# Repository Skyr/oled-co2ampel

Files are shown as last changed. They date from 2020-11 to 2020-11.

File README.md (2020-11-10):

# CO2-Ampel mit OLED-Display

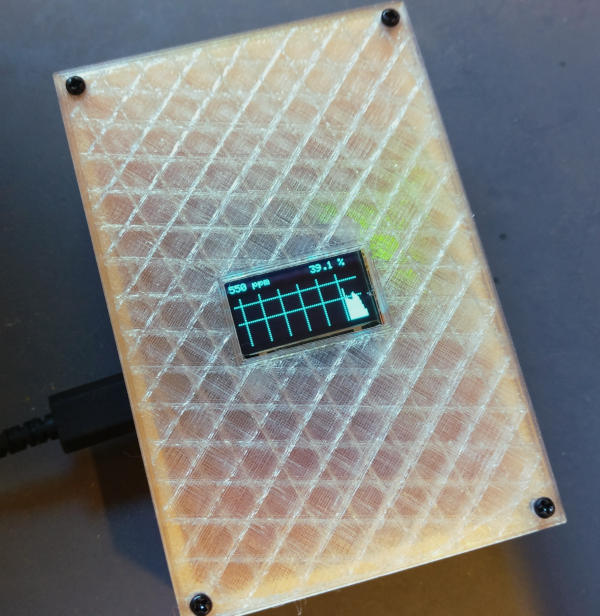
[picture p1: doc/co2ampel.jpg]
Die fertige CO2-Ampel


## Benutzung

### Selbsttest

Nach dem Einschalten führt die Software einen rudimentären Selbsttest aus. Man kann ich auch auf der seriellen Konsole beobachten. Zunächst werden alle LEDs für eine Sekunde eingeschaltet. Wenn keine Fehler auftraten, beginnt die grüne LED zu blinken, bis der erste Messwert vom CO2-Sensor vorliegt.

Andere Blinkcodes haben folgende Bedeutung:

* Rot blinkt: Fehler beim Initialisieren des I2C-Busses (Problem mit Pull-Up-Widerständen?)
* Rotes Licht, gelb blinkt: Der CO2-Sensor reagiert auf dem I2C-Bus nicht (Problem mit Lötstellen? Sensor defekt?)
* Gelb blinkt: Der CO2-Sensor konnte nicht initialisiert werden

### Anzeige

Nach dem Selbsttest geht das Program in den „Ampelmodus“ und aktualisiert alle 15 Sekunden Display und Ampelstatus.
Auf dem Display sieht man die aktuell gemessene CO2-Konzentration sowie die relative Luftfeuchte. Die Balkengrafik zeigt die Historie der Messwerte an. Die senkrechten unterbrochenen Linien sind im Abstand von 5 Minuten dargestellt. Die waagrechten unterbrochenen Linien sind die Schwellwerte für gelbes und rotes Warnlicht.

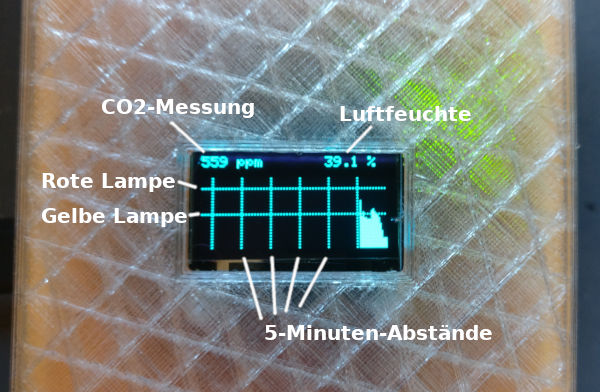
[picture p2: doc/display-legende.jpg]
Display-Legende


### Kalibrieren

Die automatische Kalibrierung des SCD30 erfordert einen ununterbrochenen Betrieb über mindestens 7 Tage hinweg, wobei an jedem Tag mindestens eine Stunde frische Außenluft an den Sensor kommen muss.
Da dies für die üblichen Belange unpraktikabel ist, ist die automatische Kalibrierung abgeschaltet. Stattdessen kann die Kalibrierung von Hand erfolgen:
Hierzu bringt man die CO2-Ampel an frische (bewegungslose) Außenluft (von der angenommen wird, dass sie 406 ppm CO2 enthält) und wartet einige Minuten, bis sich die Messwerte stabilisiert haben.
Nun verbindet man den Pin D3 mit GND (entweder durch Anbringen eines Tasters, oder provisorisch mit z.B. einem Dupont-Kabel). Als Quittung leuchtet die LED des ESP-Moduls. Blinkt sie und erlischt, ist die Kalibrierung abgeschlossen.

## Selber bauen

### Bauteile

* [Octopus-SCD30-Bundle](https://www.tindie.com/products/FabLab/diy-octopus-scd30-bundle-kit/) von Guido Burger
* 0,96" Monochrom-OLED I2C Display-Modul - z.B. von [Amazon](https://www.amazon.de/-/en/AZDelivery-OLED-Parent-Pixel-Inches/dp/B01L9GC470/) oder [AliExpress](https://www.aliexpress.com/item/32638662748.html)
* 12 M2-Schräubchen (3 - 5 mm lang) zum Befestigen der Teile und des Deckels.
* Lötequipment, etwas Kabel zum Anschluss des Displays

### 3d-Gehäuse drucken

Im Verzeichnis 3dprint befinden sie die STL-Dateien für Deckel und Gehäuse,
sowie der Quelltext zur Bearbeitung in [OpenSCAD](https://www.openscad.org/). Beim Druck sollte eine Layer Height von 0,3 genügen (geht schneller ;-).
Für den Deckel sollte ein möglichst durchscheinendes Filament verwendet werden, damit man die Ampel-LEDs gut sieht.

### Zusammenbau

Octopus-Platine nach Anleitung zusammenlöten: Mit den flachen Bauteilen beginnen, etc. Wer will, kann die LED-Beinchen möglichst lange lassen, so dass sie möglichst dicht an den Gehäusedeckel ragen (deshalb das Gehäuse vorher drucken, um die Länge abschätzen zu können) - der man modifiziert das Gehäuse und platziert die LEDs in Aussparungen.

Kabel zum Display befestigen: Diese werden an GND, 5V, D1 und D2 angelötet:

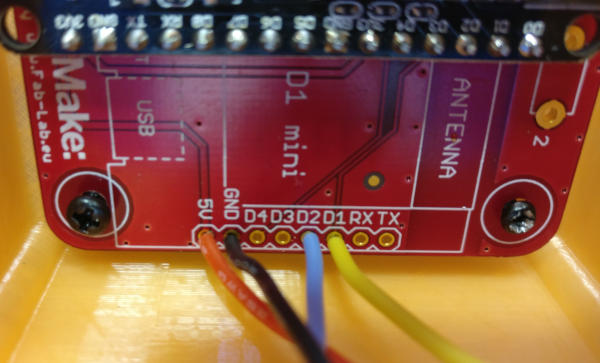
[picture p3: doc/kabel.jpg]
Kabel an der Octopus-Platine


Diese werden am Display-Modul angelötet: 5V führt an VCC, D1 an SCL, D2 an SDA (Beschriftung am Display-Modul beachten! Die sind je nach Hersteller nicht immer in der dargestellten Reihenfolge!)

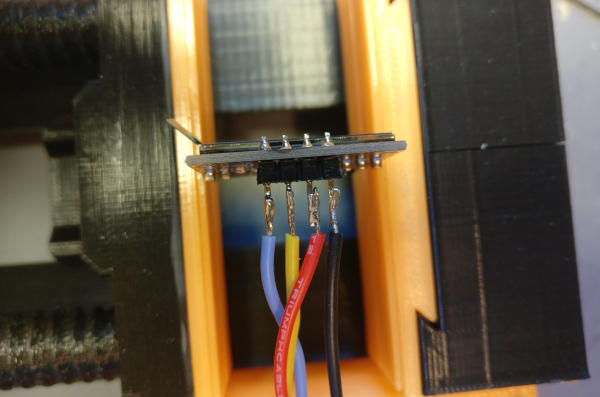
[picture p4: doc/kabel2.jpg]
Kabel am Display-Modul


Nun kann das Display (und, wenn noch nicht geschehen, die Platine) vorsichtig am Gehäuse befestigt werden (beim Display aufpassen, dass man das Glas nicht irgendwo verkantet - es bricht sehr leicht)

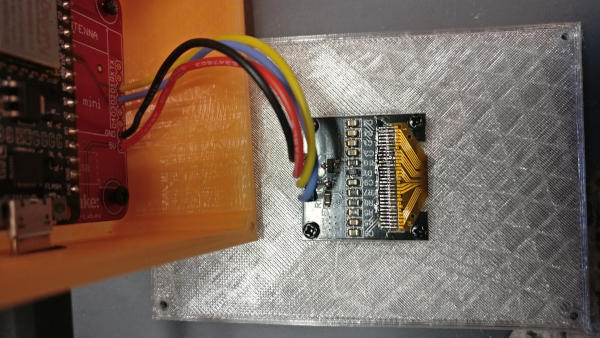
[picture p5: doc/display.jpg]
Displaymodul befestigen


Nun den Deckel auf der Box mit Schrauben befestigen.

### Aufspielen der Firmware

Da die Platine keinen Luftdrucksensor besitzt, sollte vor dem Übersetzen die Konstante `ALTITUDE` auf die (ungefähre) Höhe über NN des Einsatzortes gesetzt werden.
Die Software lässt sich mit dem [PlatformIO-Plugin](https://platformio.org/) in VSCode übersetzen und auf den ESP spielen.  Standardmäßig sind die Schwellwerte für gelb auf 1000 ppm und rot auf 1500 ppm konfiguriert. Dies lässt sich mit den entsprechenden Konstanten anpassen.

## Lizenz

Dieses Projekt (Software, 3D-Modell) steht unter der [Creative-Comons-Lizenz Namensnennung-Nicht kommerziell-Share Alike 4.0 International](https://creativecommons.org/licenses/by-nc-sa/4.0/deed.de).

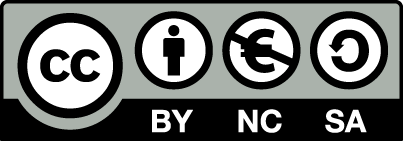
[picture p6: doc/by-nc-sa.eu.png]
CC by-nc-sa


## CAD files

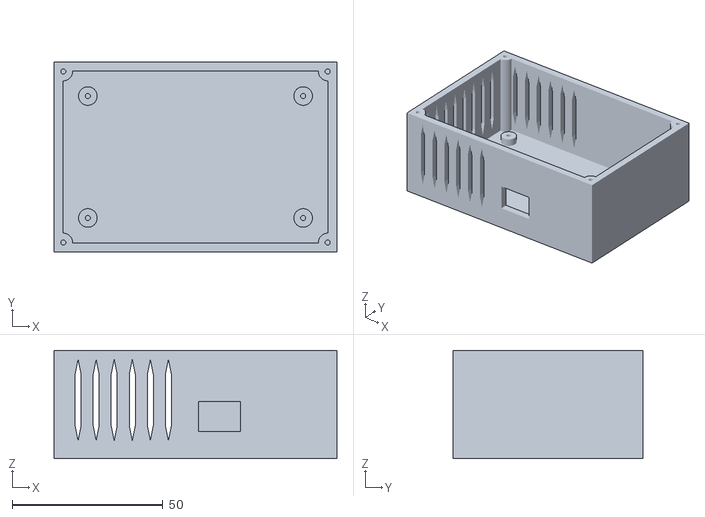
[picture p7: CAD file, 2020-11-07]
3dprint/co2ampel-case-box.stl
94.0 x 63.0 x 36.0

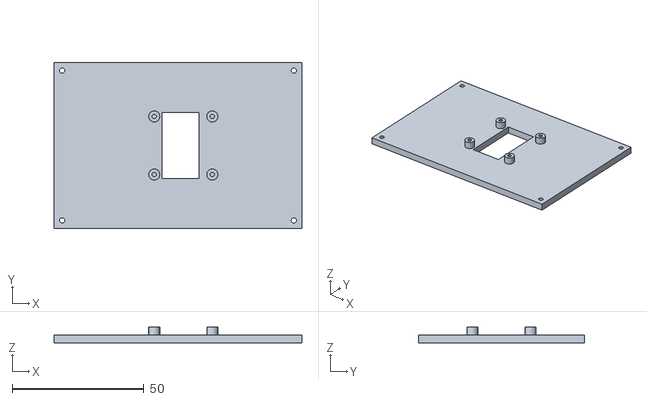
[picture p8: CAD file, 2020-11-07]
3dprint/co2ampel-case-lid.stl
94.0 x 63.0 x 6.00

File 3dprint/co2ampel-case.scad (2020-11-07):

// Written by Stefan Schlott
// Licensed under Creative Commons Attribution-NonCommercial-ShareAlike 4.0 International

wall_thickness = 3;
screw_size = 2; // M2 screw
screwhole_size = 1.7;  // For M2 screws
screwblock_diam = 1.5*wall_thickness + screwhole_size;
board_x = 82;
board_y = 51;
board_spacing = 3;
screw_height = 3;

module screw_opening(height) {
    translate([0,0,height/2]) 
        cylinder(height, d=screw_size, center=true, $fn=30);
}

module screw_hole(height) {
    translate([0,0,height/2]) 
        cylinder(height, d=screwhole_size, center=true, $fn=30);
}

module screw_block(height, diam=screwblock_diam) {
    translate([0,0,height/2]) cylinder(height, d=diam, center=true, $fn=30);
}

module screw_mount(height, diam=screwblock_diam) {
    difference() {
        screw_block(height, diam);
        screw_hole(height);
    }
}

module ventilation_slit(height) {
    width=2;
    translate([0,wall_thickness,0])
    rotate([90,0,0])
    linear_extrude(height=wall_thickness)
        polygon(points=[ [0,0], [-width/2, 5], [-width/2,height-5], [0,height], [width/2,height-5],[width/2,5] ]);
}

module box() {
    board_screw_offset = 5.25;
    electronics_height = 30;

    module outer_box() {
        difference() {
            cube([2*wall_thickness + 2*board_spacing + board_x,
                2*wall_thickness + 2*board_spacing + board_y,
                wall_thickness + screw_height + electronics_height ]);
            translate([wall_thickness,wall_thickness,wall_thickness])
                cube([2*board_spacing + board_x,
                    2*board_spacing + board_y,
                    screw_height + electronics_height ]);
        }
    }

    // Outer box with screw holes
    difference() {
        union() {
            outer_box();
            for (i=[0:1]) {
                for (j=[0:1]) {
                    translate([screwblock_diam/2 + i*(2*wall_thickness + 2*board_spacing + board_x-screwblock_diam), 
                        screwblock_diam/2 + j*(2*wall_thickness + 2*board_spacing + board_y-screwblock_diam),
                        wall_thickness])
                            screw_block(screw_height + electronics_height);
                }
            }
        }
        // Holes for screws
        for (i=[0:1]) {
            for (j=[0:1]) {
                translate([screwblock_diam/2 + i*(2*wall_thickness + 2*board_spacing + board_x-screwblock_diam), 
                    screwblock_diam/2 + j*(2*wall_thickness + 2*board_spacing + board_y-screwblock_diam),
                    wall_thickness + electronics_height ])
                        screw_hole(screw_height);
            }
        }
        // USB opening
        usb_width = 14;
        usb_height = 10;
        translate([wall_thickness+board_spacing+49-(usb_width/2),0,wall_thickness+screw_height+8-(usb_height/2)]) cube([usb_width,wall_thickness,usb_height]);
        // Ventilation slits
        for (i=[0:5]) {
            translate([wall_thickness+board_spacing+2+i*6,0,wall_thickness+screw_height])
                ventilation_slit(electronics_height-screw_height);
            translate([wall_thickness+board_spacing+2+i*6,wall_thickness+2*board_spacing+board_y,wall_thickness+screw_height])
                ventilation_slit(electronics_height-screw_height);
        }
        for (i=[0:7]) {
            translate([wall_thickness,wall_thickness+board_spacing+board_y/2-1+(i-3.5)*6,wall_thickness+screw_height])
            rotate([0,0,90])
                ventilation_slit(electronics_height-screw_height);
        }
    }
    
    translate([0,0,wall_thickness]) {
        for (i=[0:1]) {
            for (j=[0:1]) {
                translate([wall_thickness+board_spacing+board_screw_offset + i*(board_x-2*board_screw_offset),
                    wall_thickness+board_spacing+board_screw_offset + j*(board_y-2*board_screw_offset),
                    0]) screw_mount(screw_height);
            }
        }
    }
    
    // For reference: Board
    //translate([wall_thickness+board_spacing, wall_thickness+board_spacing, wall_thickness+screw_height]) 
    //    color("red")    
    //    cube([board_x, board_y, 2]);
}


module lid() {
    thickness = wall_thickness;
    display_x_ofs = 32;  // Offset from top of board
    display_x_out_of_center = 1;  // Display not exactly in middle of board...
    display_x = 14;
    display_y = 25;
    screw_x_ofs = 4;
    screw_y_ofs = 1.5;
    
    difference() {
        cube([2*wall_thickness + 2*board_spacing + board_x,
            2*wall_thickness + 2*board_spacing + board_y,
            thickness]);
        // Screw holes for mounting the lid
        for (i=[0:1]) {
            for (j=[0:1]) {
                translate([screwblock_diam/2 + i*(2*wall_thickness + 2*board_spacing + board_x-screwblock_diam), 
                    screwblock_diam/2 + j*(2*wall_thickness + 2*board_spacing + board_y-screwblock_diam),
                    0 ])
                        screw_opening(thickness);
            }
        }
        // Display opening
        translate([wall_thickness + board_spacing + display_x_ofs + display_x_out_of_center,(2*wall_thickness + 2*board_spacing + board_y - display_y)/2,0])
            cube([display_x,display_y,thickness]);
    }
    // Screw mounts for display
    translate([wall_thickness + board_spacing + display_x_ofs,(2*wall_thickness + 2*board_spacing + board_y - display_y)/2,-screw_height]) {
        translate([-screw_x_ofs,screw_y_ofs,0]) screw_mount(screw_height, diam = screwhole_size + 2.5);
        translate([display_x+screw_x_ofs,screw_y_ofs,0]) screw_mount(screw_height, screwhole_size + 2.5);
        translate([-screw_x_ofs,display_y-screw_y_ofs,0]) screw_mount(screw_height, screwhole_size + 2.5);
        translate([display_x+screw_x_ofs,display_y-screw_y_ofs,0]) screw_mount(screw_height, screwhole_size + 2.5);
    }
}


translate([0,0,-30 - 20])
    box();
// rotate([0,180,0])
    lid();

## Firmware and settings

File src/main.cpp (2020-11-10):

// Written by Stefan Schlott
// Licensed under Creative Commons Attribution-NonCommercial-ShareAlike 4.0 International


#include <Arduino.h>
#include <Wire.h>

#include <SparkFun_SCD30_Arduino_Library.h>
#include <Adafruit_SSD1306.h>
#include <Adafruit_GFX.h>

// OLED display size, in pixels
#define SCREEN_WIDTH 128
#define SCREEN_HEIGHT 64

Adafruit_SSD1306 display(SCREEN_WIDTH, SCREEN_HEIGHT, &Wire);
SCD30 airSensor;
uint16_t co2buffer[SCREEN_WIDTH+1];

// Pin definitions
#define LED_RED     D6
#define LED_YELLOW  D7
#define LED_GREEN   D5
#define I2C_SCL     D1
#define I2C_SDA     D2
#define CAL_BUTTON  D3

// Altitude (in meters). Atmospheric pressure (and thus the measurement) drops by 3% for every ~300m!
#define ALTITUDE 445
// Number of seconds between measurements
#define UPDATE_INTERVAL 15

#define CO2_BAR_MIN 350
#define CO2_BAR_MAX 1700
#define YELLOW_THRESHOLD 1000
#define RED_THRESHOLD 1500


bool display_enabled = false;
bool do_calibration = false;
unsigned long last_calibration = 0;


void ledsOff() {
    digitalWrite(LED_RED, LOW);
    digitalWrite(LED_YELLOW, LOW);
    digitalWrite(LED_GREEN, LOW);
}

void blink(int pin, int d) {
    digitalWrite(pin, HIGH);
    delay(d);
    digitalWrite(pin, LOW);
    delay(d);
}

void blinkFail(int pin) {
    while (true) {
        blink(pin, 500);
    }
}

void selfCheck() {
    // Internal LED on
    digitalWrite(LED_BUILTIN, LOW);
    // All LEDs on
    digitalWrite(LED_RED, HIGH);
    digitalWrite(LED_YELLOW, HIGH);
    digitalWrite(LED_GREEN, HIGH);
    Serial.println("All LEDs on");
    delay(1000);
    
    // All LEDs off
    ledsOff();
    Serial.println("All LEDs off");
    delay(500);
 
    // I2C pull-up check
    bool checkFailed = false;
    if (digitalRead(I2C_SCL) != HIGH) {
        Serial.println("Pull-up check for I2C SCL failed");
        checkFailed = true;
    }
    if (digitalRead(I2C_SDA) != HIGH) {
        Serial.println("Pull-up check for I2C SDA failed");
        checkFailed = true;
    }
    if (checkFailed) {
        // Blink red led infinitely
        blinkFail(LED_RED);
    }
 
    // I2C communication check
    Wire.begin();
    Wire.beginTransmission(SCD30_ADDRESS);
    if (Wire.endTransmission() != 0) {
        Serial.println("Failed to start I2C communication with SCD30 module");
        digitalWrite(LED_RED, HIGH);
        blinkFail(LED_YELLOW);       
    }
    delay(200);

    airSensor.begin(false);  // No auto calibration
    delay(500);
    if (!airSensor.beginMeasuring()) {
        Serial.println("Failed to initialize SCD30 module");
        blinkFail(LED_YELLOW);
    }
    if (ALTITUDE>0) {
        if (!airSensor.setAltitudeCompensation(ALTITUDE)) {
            Serial.println("Failed to set altitude compensation");
        }
    } else {
        airSensor.setAltitudeCompensation(0);
    }

    // Init display
    if(display.begin(SSD1306_SWITCHCAPVCC, 0x3C, true)) {
        display.clearDisplay();
        display.display();
        display_enabled = true;
    } else {
        Serial.println("Failed to initialize display");
        display_enabled = false;
    }

    // Internal LED off
    digitalWrite(LED_BUILTIN, HIGH);
    // All good!
    Serial.println("Starting up, waiting for first data...");
    for (int i=0; i<3; i++) {
        blink(display_enabled ? LED_GREEN : LED_YELLOW, 300);
    }
    // Continue blinking until data available
    while (!airSensor.dataAvailable()) {
        blink(LED_GREEN, 300);
    }
}

inline void ICACHE_RAM_ATTR isr_calButtonChanged() {
    // Avoid triggering too soon
    if (millis()-last_calibration>5000) {
        do_calibration = true;
        // As confirmation: Turn on internal LED
        digitalWrite(LED_BUILTIN, LOW);
    }
}


void setup() {
    Serial.begin(115200);

    // Empty buffer
    memset(co2buffer, 0, sizeof(co2buffer));

    // Setup pins
    pinMode(LED_BUILTIN, OUTPUT);
    pinMode(I2C_SCL, INPUT);
    pinMode(I2C_SDA, INPUT);
    pinMode(CAL_BUTTON, INPUT);
    pinMode(LED_RED, OUTPUT);
    pinMode(LED_YELLOW, OUTPUT);
    pinMode(LED_GREEN, OUTPUT);

    // Self check
    selfCheck();

    // Final initialization
    ledsOff();
    attachInterrupt(digitalPinToInterrupt(CAL_BUTTON), isr_calButtonChanged, FALLING);
    airSensor.setMeasurementInterval(UPDATE_INTERVAL);
}

#define BAR_MAX_LEN (SCREEN_HEIGHT - 15)

uint16_t barLen(uint16_t co2) {
    if (co2<CO2_BAR_MIN) {
        return 0;
    }
    if (co2>CO2_BAR_MAX) {
        return BAR_MAX_LEN;
    }
    return (co2 - CO2_BAR_MIN) * BAR_MAX_LEN / (CO2_BAR_MAX - CO2_BAR_MIN);
}


void loop() {
    uint16_t co2 = 0;
    float humidity = 0;

    // Calibration
    if (do_calibration) {
        last_calibration = millis();
        // Calibration to fresh air
        airSensor.setForcedRecalibrationFactor(406);
        // Reset flag
        do_calibration = false;
        // Flash internal LED as confirmation
        for (int i=0; i<3; i++) {
            blink(LED_BUILTIN, 500);
        }
        digitalWrite(LED_BUILTIN, HIGH);
    }

    // If data not yet available (clock drift?): Wait a moment
    int retries = 5;
    while (!airSensor.dataAvailable() && retries>0) {
        delay(500);
    }

    // Read data
    if (airSensor.dataAvailable()) {
        co2 = airSensor.getCO2();
        humidity = airSensor.getHumidity();

        digitalWrite(LED_RED, (co2 >= RED_THRESHOLD) ? HIGH : LOW);
        digitalWrite(LED_YELLOW, (co2 > YELLOW_THRESHOLD && co2 < RED_THRESHOLD) ? HIGH : LOW);
        digitalWrite(LED_GREEN, (co2 <= YELLOW_THRESHOLD) ? HIGH : LOW);
        

        Serial.print("co2(ppm): ");
        Serial.print(co2);

        Serial.print("  temp(C): ");
        Serial.print(airSensor.getTemperature(), 1);

        Serial.print("  humidity(%): ");
        Serial.print(humidity, 1);

        Serial.println();
    }

    // Update data
    co2buffer[SCREEN_WIDTH] = co2;
    if (display_enabled) {
        // Update chart
        for (int i=0; i<SCREEN_WIDTH; i++) {
            uint16_t old_len = barLen(co2buffer[i]);
            uint16_t new_len = barLen(co2buffer[i+1]);
            if (old_len!=new_len) {
                if (old_len<new_len) {
                    display.drawFastVLine(i, SCREEN_HEIGHT - 1 - new_len, new_len-old_len+1, WHITE);
                } else {
                    display.drawFastVLine(i, SCREEN_HEIGHT - 1 - old_len, old_len-new_len+1, BLACK);
                }
            }
        }
    }
    // Roll buffer
    for (int i=0; i<SCREEN_WIDTH; i++) {
        co2buffer[i] = co2buffer[i+1];
    }
    if (display_enabled) {
        // Draw 5 min lines
        for (int x=SCREEN_WIDTH-1-(300/UPDATE_INTERVAL); x>0; x-=300/UPDATE_INTERVAL) {
            uint16_t len = barLen(co2buffer[x]);
            for (int y=SCREEN_HEIGHT - BAR_MAX_LEN; y<SCREEN_HEIGHT - len; y+=2) {
                display.drawPixel(x, y, WHITE);
            }
        }
        // Draw line for yellow warning
        for (int x=0; x<SCREEN_WIDTH; x+=2) {
            display.drawPixel(x, SCREEN_HEIGHT - 1 - barLen(YELLOW_THRESHOLD), WHITE);
        }
        // Draw line for red warning
        for (int x=0; x<SCREEN_WIDTH; x+=2) {
            display.drawPixel(x, SCREEN_HEIGHT - 1 - barLen(RED_THRESHOLD), WHITE);
        }
        // Show text
        display.fillRect(0, 0, SCREEN_WIDTH, SCREEN_HEIGHT - BAR_MAX_LEN, BLACK);
        display.setTextSize(1);
        display.setCursor(0, 0);
        display.setTextColor(WHITE);
        display.printf("%d ppm", co2);
        display.setCursor(SCREEN_WIDTH * 2 / 3, 0);
        display.printf("%02.1f %%", humidity);
        display.display();
    }

    // Wait
    delay(UPDATE_INTERVAL * 1000);
}

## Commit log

2020-11-03 Startup: Continue blinking until sensor is ready
2020-11-05 Altitude correction. Disable targets not matching Octopus hardware
    [main.cpp]
2020-11-05 Case: Lower part
    [co2ampel-case.scad]
2020-11-05 Ventilation openings
    [co2ampel-case.scad]
2020-11-07 Thicker lid
    [co2ampel-case.scad]
2020-11-07 Correct position of display opening
    [co2ampel-case.scad]
2020-11-07 Add stl renderings
    [co2ampel-case-box.stl, co2ampel-case-lid.stl]
2020-11-07 Add documentation and license info
    [co2ampel-case.scad]
2020-11-10 Manual calibration
